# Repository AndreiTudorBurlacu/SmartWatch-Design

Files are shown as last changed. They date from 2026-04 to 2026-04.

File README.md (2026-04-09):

# Design Smartwatch

A smartwatch based on the Nordic nRF52840 microcontroller with an e-Paper display.
---

## Diagrama bloc

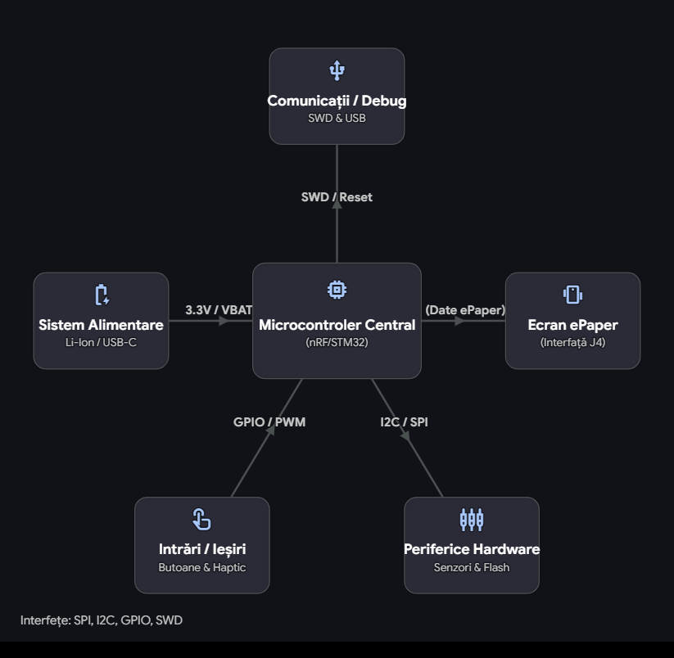
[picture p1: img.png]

---

## Bill of Materials

| Ref | Componenta | Valoare | JLC Parts | Datasheet |
|-----|---|---|---|---|
| U1 | nRF52840 | $5.12 | [JLC](https://jlcpcb.com/parts/componentSearch?searchTxt=nRF52840-QF) | [DS](https://jlcpcb.com/api/file/downloadByFileSystemAccessId/8589839228197629952) |
| X1 | NX2016SA-32MHZ-EXS00A-CS11336 | $9.06 | [JLC](https://jlcpcb.com/partdetail/NDK-NX2016SA_32MHZ_EXS00ACS11336/C6134317) | [DS](https://jlcpcb.com/api/file/downloadByFileSystemAccessId/8603064888214908928) |
| X2 | FC-135_32.7680KA-A3 | $0.2923 | [JLC](https://jlcpcb.com/partdetail/SeikoEpson-FC_135_32_7680KAA3/C2650472) | [DS](https://jlcpcb.com/partdetail/SeikoEpson-FC_135_32_7680KAA3/C2650472) |
| L2 | RC0402JR-070RL | $0.02 | [JLC](https://jlcpcb.com/partdetail/YAGEO-RC0402JR070RL/C60485) | [DS](https://jlcpcb.com/api/file/downloadByFileSystemAccessId/8717146932348461056) |
| L3 | RC0402JR-070RL | $0.01 | [JLC](https://jlcpcb.com/partdetail/YAGEO-RC0402JR070RL/C60485) | [DS](https://jlcpcb.com/api/file/downloadByFileSystemAccessId/8717146932348461056) |
| L5 | 744043680 | $9.33 | [JLC](https://jlcpcb.com/partdetail/WurthElektronik-744043680/C2045671) | [DS](https://www.we-online.com/components/products/datasheet/744043680.pdf) |
| L7 | MLP2016SR47MT0S1 | $0.9 | [JLC](https://jlcpcb.com/partdetail/TDK-MLP2016SR47MT0S1/C87545) | [DS](https://jlcpcb.com/api/file/downloadByFileSystemAccessId/8588933367512879104) |
| IC1 | BQ25180YBGR | $2.04 | [JLC](https://jlcpcb.com/partdetail/TexasInstruments-BQ25180YBGR/C3682423) | [DS](https://www.ti.com/cn/lit/gpn/bq25180) |
| IC2 | DRV2605YZFR | $1.61 | [JLC](https://jlcpcb.com/partdetail/TexasInstruments-DRV2605YZFR/C81079) | [DS](https://www.ti.com/cn/lit/gpn/drv2605) |
| IC3 | BMA423 | $12.30  | [JLC](https://jlcpcb.com/partdetail/BoschSensortec-BMA423/C189517) | [DS](https://jlcpcb.com/api/file/downloadByFileSystemAccessId/8588894317147017216) |
| IC9 | RT6160 | $0.46 | [JLC](https://jlcpcb.com/partdetail/RichtekTech-RT6160AWSC/C7065276) | [DS](https://jlcpcb.com/api/file/downloadByFileSystemAccessId/8600398231234883584) |
| ANT1 | 2450AT18B100E | $1.04 | [JLC](https://jlcpcb.com/partdetail/JohansonDielectrics-2450AT18B100E/C2917717) | [DS](https://jlcpcb.com/api/file/downloadByFileSystemAccessId/8588940948130156544) |
| D2 | MBR0530 | $0.02 | [JLC](https://jlcpcb.com/partdetail/78464-MBR0530/C77336) | [DS](https://jlcpcb.com/api/file/downloadByFileSystemAccessId/8586175081181818880) |
| D3 | USBLC6-2SC6Y | $0.23 | [JLC](https://jlcpcb.com/partdetail/STMicroelectronics-USBLC62SC6Y/C2969755) | [DS](https://jlcpcb.com/api/file/downloadByFileSystemAccessId/8603165824304111616) |
| D4 | MBR0530 | $0.03 | [JLC](https://jlcpcb.com/partdetail/78464-MBR0530/C77336) | [DS](https://jlcpcb.com/api/file/downloadByFileSystemAccessId/8586175081181818880) |
| D5 | MBR0530 | $0.04 | [JLC](https://jlcpcb.com/partdetail/78464-MBR0530/C77336) | [DS](https://jlcpcb.com/api/file/downloadByFileSystemAccessId/8586175081181818880) |
| Q1 | DMG2305UX-7 | $0.15 | [JLC](https://jlcpcb.com/partdetail/DiodesIncorporated-DMG2305UX7/C150470) | [DS](https://jlcpcb.com/api/file/downloadByFileSystemAccessId/8560079443617075200) |
| Q3 | SI1308EDL-T1-GE3 | $0.15 | [JLC](https://jlcpcb.com/partdetail/VishayIntertech-SI1308EDL_T1GE3/C469327) | [DS](https://jlcpcb.com/api/file/downloadByFileSystemAccessId/8588884784742846464) |
| J1 | 503480-2400 | $0.67 | [JLC](https://jlcpcb.com/partdetail/MOLEX-5034802400/C122434) | [DS](https://www.molex.com/content/dam/molex/molex-dot-com/products/automated/en-us/salesdrawingpdf/503/503480/5034802400_sd.pdf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) |
| J4 | KH-TYPE-C-16P | $0.05 | [JLC](https://jlcpcb.com/partdetail/Shenzhen_KinghelmElec-KH_TYPE_C16P/C709357) | [DS](https://jlcpcb.com/api/file/downloadByFileSystemAccessId/8588905154556923904) |
| U3 | MAX17048G-T10 | $2.76 | [JLC](https://jlcpcb.com/partdetail/2777647-MAX17048GT10/C2682616) | [DS](https://jlcpcb.com/api/file/downloadByFileSystemAccessId/8588907428524003328) |
| SWD | TC2030-IDC | $101.26 | [JLC](https://jlcpcb.com/partdetail/MicrochipTech-TC2030_CLIP3PACK/C5444772) | [DS](https://www.lcsc.com/datasheet/lcsc_datasheet_2403201318_Microchip-Tech-TC2030-CLIP-3PACK_C5444772.pdf) |

---

## Descriere Functionalitati Hardware

### Microcontroller - nRF52840

Arhitectura:
- Procesor ARM Cortex-M4 cu FPU ruland la 64 MHz
- 1 MB memorie Flash si 256 KB RAM
- Suport nativ pentru Bluetooth 5, Bluetooth Low Energy (BLE), Thread si Zigbee
- Dispune de USB 2.0 (Full Speed), SPI, I2C, UART si QSPI
 
### Display E-Paper - Waveshare 1.54" V2
 
Display-ul comunica prin SPI pe 4 fire:
- Rezolutie: 200x200 pixeli
- Interfata comunicare: SPI
- Consum de energie ultra-redus; consuma aproximativ 26.4 mW doar in timpul reimprospatarii si scade sub 0.01 uA in modul standby
- Suporta partial refresh (reimprospatarea doar a unei anumite zone din ecran)
 
### IMU - BMA423
 
Accelerometrul BMA423 comunica prin I2C:

- Tip senzor: Accelerometru digital pe 3 axe.
- Rezolutie date - 12 biti
- Interfete comunicare: I2C si SPI
- Consum foarte eficient, trage in jur de 14 uA cand se afla in modul activ de numarare a pasilor
 
### Incarcator Baterie - BQ25180

- Dimensiuni: 32.5mm x 21mm x 5.5mm
- Curent de incarcare: Flexibil, poate incarca de la cativa miliamperi pana la 1 A
- Interfata control: Comunicare I2C prin care procesorul principal poate citi statusul bateriei si poate modifica parametrii de incarcare din mers
- Tensiune standard de intrare de 5V, dar are protectie la supratensiune (OVP) care rezista pana la 25V
 
### Baterie - AKYGA LP502030
 
- Tensiune - 3.7V nominal (ajunge la 4.2V cand este incarcata 100% si scade spre 3.0V cand este descarcata)
- Capacitate: Aproximativ 250 mAh
- Dimensiuni - 5 mm x 20 mm x 30 mm
 
### Motor Vibratii - FIT0774

- Tensiune de operare: 3V curent continuu
- Curent maxim consumat - 85 mA in momentul in care vibreaza la capacitate maxima
- Viteza de rotatie: Aproximativ 12000 RPM
- 10 mm diametru si o grosime de doar 2.7 mm
 
### Conector Debug - TC2030-IDC
 
- Tip contact: 6 pini cu arc (pogo-pins) dispusi pe 2 randuri, cu o distanta de 1.27 mm intre ei
- Folosit pentru programare si debugging SWD
- Semnale: SWDIO, SWDCLK, GND, VCC, RESET
 
---
 
## Pinii nRF52840
 
| Pin nRF52840 | Semnal | Componenta | Interfata |
|---|---|---|---|
| P0.00/XL1 | XL1 | Crystal X2 (32.768kHz) | XTAL |
| P0.01/XL2 | XL2 | Crystal X2 (32.768kHz) | XTAL |
| P0.05/AIN3 | EPD_CS | E-Paper (J1 FPC) | SPI CS |
| P0.06 | SDA | BMA423, BQ25180, MAX17048, DRV2605 | I2C SDA |
| P0.07 | SCL | BMA423, BQ25180, MAX17048, DRV2605 | I2C SCL |
| P0.08 | IMU_INT1 | BMA423 | GPIO Input |
| P1.08 | IMU_INT2 | BMA423 | GPIO Input |
| P0.11 | PMIC_INT | BQ25180 | GPIO Input |
| P0.12 | HAPTIC_EN | DRV2605 | GPIO |
| VBUS | VBUS | USB-C (J4) | Power |
| D- | D- | USB-C (J4) / USBLC6 | USB |
| D+ | D+ | USB-C (J4) / USBLC6 | USB |
| P0.13 | SW_UP | Buton Up | GPIO Input |
| P0.14 | SW_ENT | Buton Enter | GPIO Input |
| P0.15 | EPD_DC | E-Paper (J1 FPC) | SPI DC |
| P0.16 | EPD_RST | E-Paper (J1 FPC) | GPIO |
| P0.17 | EPD_BUSY | E-Paper (J1 FPC) | GPIO Input |
| P0.18/RESET | RESET | TC2030-IDC | SWD/GPIO |
| SWDCLK | SWDCLK | TC2030-IDC | SWD |
| SWDIO | SWDIO | TC2030-IDC | SWD |
| P1.02 | SW_DN | Buton Down | GPIO Input |
| P0.10/NFC2 | ALERT | MAX17048 | GPIO Input |
| ANT | RF | Antena 2450AT18B100E | RF |
| P0.02/AIN0 | SCK | E-Paper (J1 FPC) | SPI SCK |
| P0.03/AIN1 | MOSI | E-Paper (J1 FPC) | SPI MOSI |

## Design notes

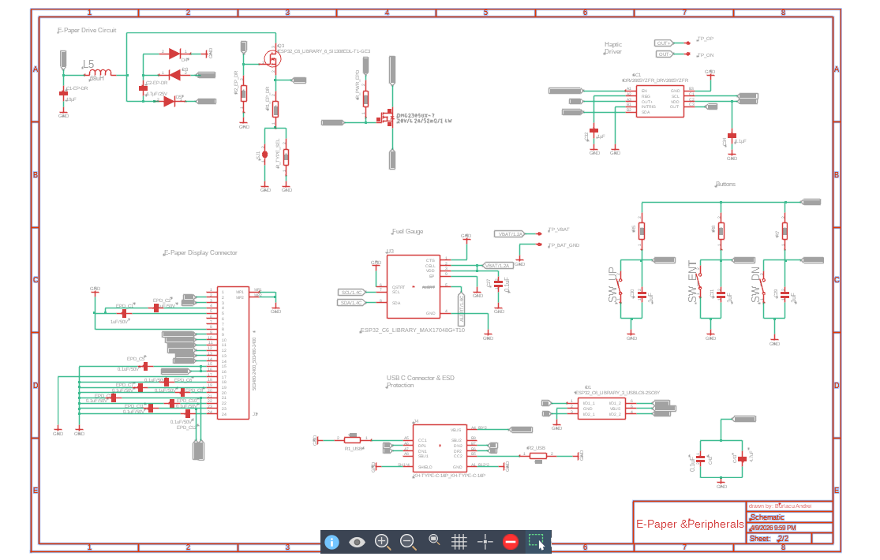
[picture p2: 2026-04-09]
Images/Schematic2.png

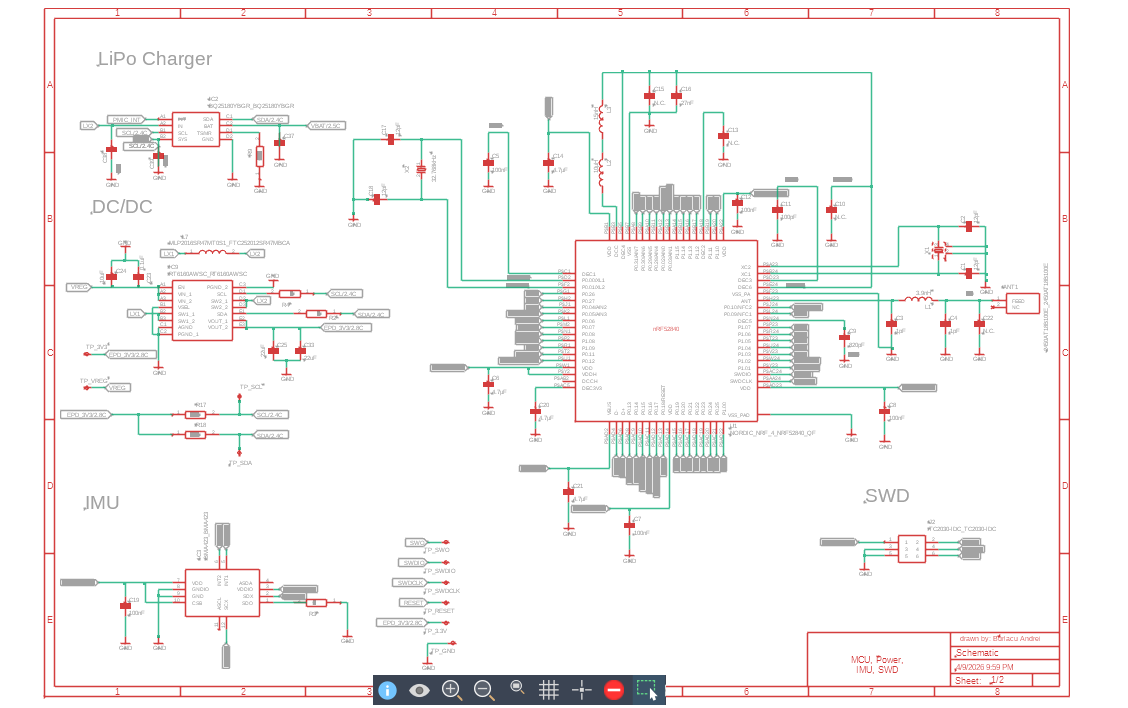
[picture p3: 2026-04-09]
Images/Schematic1.png

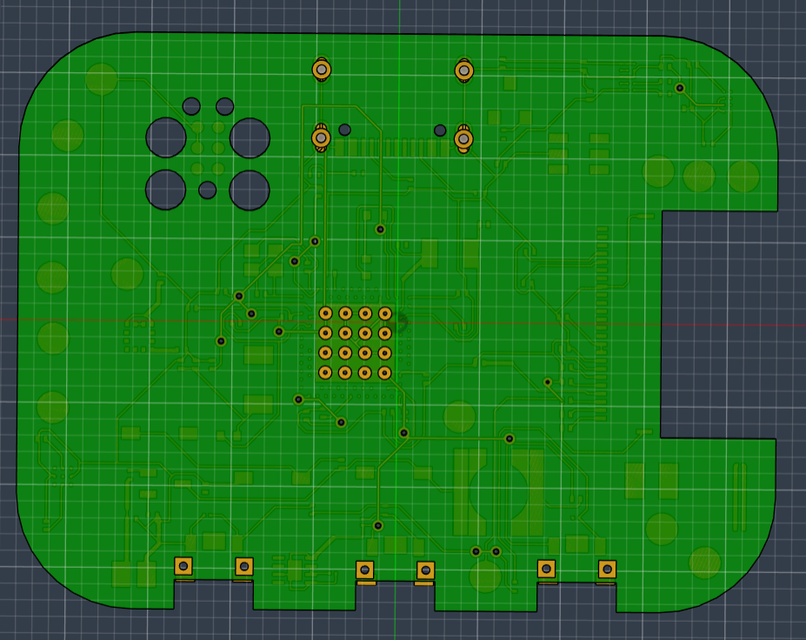
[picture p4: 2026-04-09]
Images/PCB_spate.png

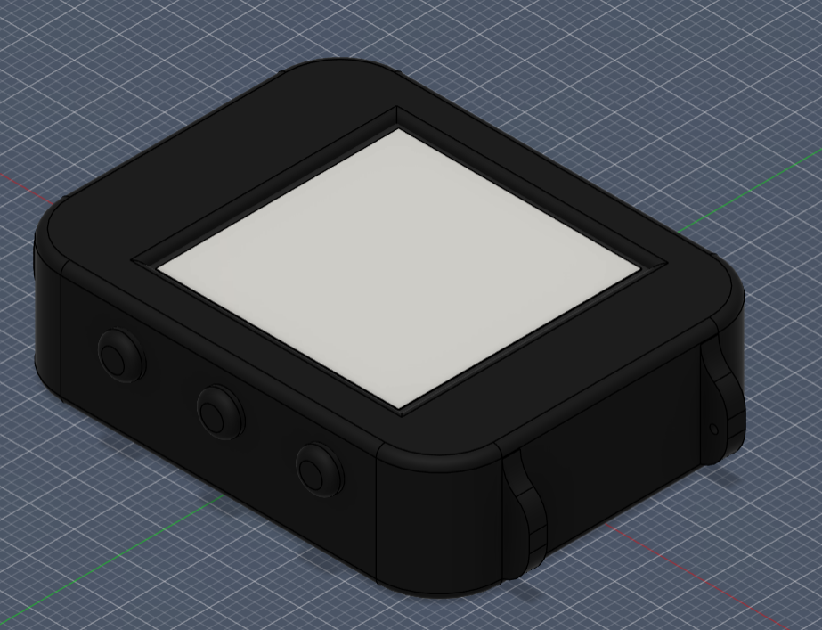
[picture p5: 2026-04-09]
Images/WatchCase3D.png

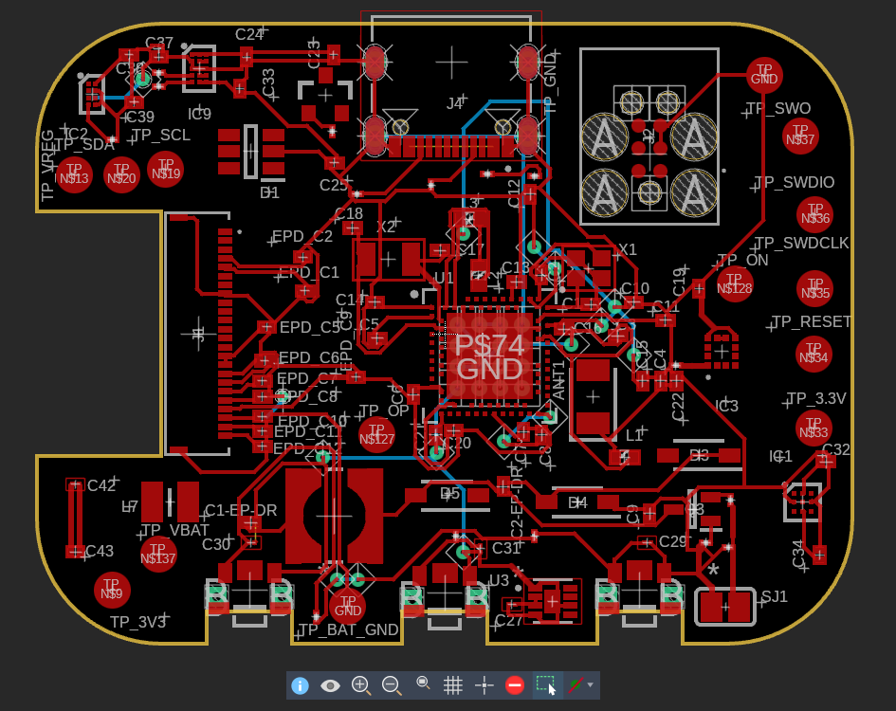
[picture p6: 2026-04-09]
Images/PCB.png

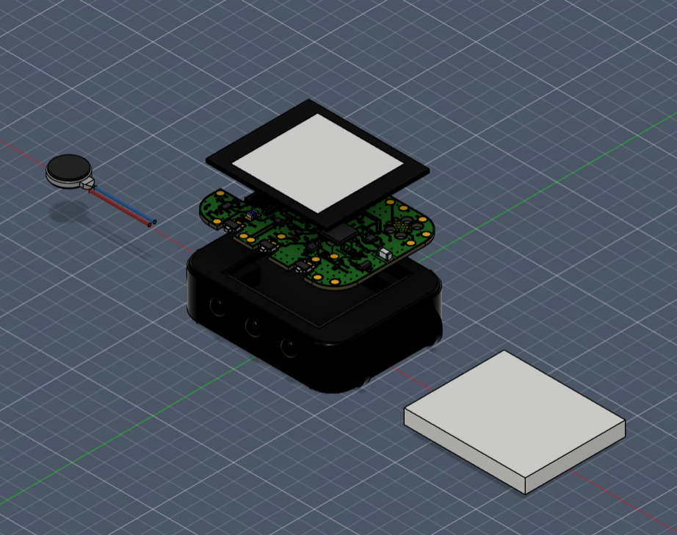
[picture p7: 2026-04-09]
Images/ExplodedView.png

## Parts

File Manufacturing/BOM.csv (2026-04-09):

Reference Designators | Quantity | Description | Package | Value | Manufacturer | Manufacturer Part Number | Vendor | Vendor Part Number | Top/Bottom
 | 1 | PCB Board | Board
ANT1 | 1 | Antennas 2.45GHz ANTENNA | 2450AT18B100E_ANTC3216X140N | 2450AT18B100E_2450AT18B100E |  |  |  |  | Top
C1, C2, C17, C18 | 4 | Generic chip capacitor | NORDIC_NRF_3_RESC0201_L | 12pF |  |  |  |  | Top
C1-EP-DR | 1 | Generic chip capacitor | NORDIC_NRF_3_RESC0201_L | 10µF |  |  |  |  | Top
C2-EP-DR | 1 | Generic chip capacitor | NORDIC_NRF_3_RESC0201_L | 4.7µF/25V |  |  |  |  | Top
C3, C4 | 2 | Generic chip capacitor | NORDIC_NRF_3_RESC0201_L | 1pF |  |  |  |  | Top
C5, C7, C8, C12, C19 | 5 | Generic chip capacitor | NORDIC_NRF_3_RESC0201_L | 100nF |  |  |  |  | Top
C6, C14, C20, C21 | 4 | Generic chip capacitor | NORDIC_NRF_3_RESC0201_L | 4.7µF |  |  |  |  | Top
C9 | 1 | Generic chip capacitor | NORDIC_NRF_3_RESC0201_L | 820pF |  |  |  |  | Top
C10, C13, C15, C22 | 4 | Generic chip capacitor | NORDIC_NRF_3_RESC0201_L | N.C. |  |  |  |  | Top
C11 | 1 | Generic chip capacitor | NORDIC_NRF_3_RESC0201_L | 100pF |  |  |  |  | Top
C16 | 1 | Generic chip capacitor | NORDIC_NRF_3_RESC0201_L | 27nF |  |  |  |  | Top
C23 | 1 | Generic chip capacitor | NORDIC_NRF_3_RESC0201_L | 0.1uF |  |  |  |  | Top
C24 | 1 | Generic chip capacitor | NORDIC_NRF_3_RESC0201_L | 10uF |  |  |  |  | Top
C25, C33 | 2 | Generic chip capacitor | NORDIC_NRF_3_RESC0201_L | 22uF |  |  |  |  | Top
C27, C29, C30, C31, C42 | 5 | Check availability | CAPC0201X13N | GRM011R60J152KE01L_2_GRM011R60J152KE01L |  |  |  |  | Top
C32 | 1 | Generic chip capacitor | NORDIC_NRF_3_RESC0201_L | 1µF |  |  |  |  | Top
C34 | 1 | Generic chip capacitor | NORDIC_NRF_3_RESC0201_L | 0.1µF |  |  |  |  | Top
C37, C38, C39 | 3 | Generic chip capacitor | NORDIC_NRF_3_RESC0201_L |  |  |  |  |  | Top
C43 | 1 | Generic chip capacitor | NORDIC_NRF_3_RESC0201_L | 4.7uF |  |  |  |  | Top
D1 | 1 | Low Cap. ESD Protection Auto SOT-23-6 STMicroelectronics USBLC6-2SC6Y, Dual Uni-Directional TVS Diode Array, 6-Pin SOT-23 | SOT95P280X145-6N | ESP32_C6_LIBRARY_3_USBLC6-2SC6Y |  |  |  |  | Top
D3, D4, D5 | 3 | ON SEMICONDUCTOR - MBR0530 - DIODE, SCHOTTKY, 0.5A, 30V, SOD-123 | SOD3716X135N | ESP32_C6_LIBRARY_5_MBR0530 |  |  |  |  | Top
DMG2305UX-7 | 1 | P-channel MOSFETs | ESP32_WROVER_SPARKFUN-DISCRETESEMI_SOT23-3 | 20V/4.2A/52mΩ/1.4W |  |  |  |  | Top
EPD_C1, EPD_C2 | 2 | Generic chip capacitor | NORDIC_NRF_3_RESC0201_L | 1uF/50V |  |  |  |  | Top
EPD_C5, EPD_C6, EPD_C7, EPD_C8, EPD_C9, EPD_C10, EPD_C11, EPD_C12 | 8 | Generic chip capacitor | NORDIC_NRF_3_RESC0201_L | 0.1uF/50V |  |  |  |  | Top
IC1 | 1 | Haptic Driver for ERM/LRA with Built-In Library and Smart Loop Architecture | DRV2605YZFR_BGA9C50P3X3_144X144X62 | DRV2605YZFR_DRV2605YZFR |  |  |  |  | Top
IC2 | 1 | Charger IC Lithium Ion/Polymer, Lithium Iron Phosphate 8-DSBGA (1.6x1.1) | BQ25180YBGR_BGA8C40P2X4_100X155X50 | BQ25180YBGR_BQ25180YBGR |  |  |  |  | Top
IC3 | 1 | Accelerometers Triaxial low-g 12bit Acceleration Sensor | BMA423_BMA423 | BMA423_BMA423 |  |  |  |  | Top
IC9 | 1 | Buck-Boost Regulator Positive Output Step-Up/Step-Down I2C DC-DC Controller IC 15-WL-CSP (BSC) (1.4x2.3) | RT6160AWSC_BGA15C40P3X5_140X230X60 | RT6160AWSC_RT6160AWSC |  |  |  |  | Top
J1 | 1 | FFC & FPC Connectors 0.5mm FPC RA SMT Dual Contact 24Ckt | 503480-2400_5034802400 | 503480-2400_503480-2400 |  |  |  |  | Top
J2 | 1 | CABLE ADAPTER 6 POS | TC2030-IDC_TC2030IDC | TC2030-IDC_TC2030-IDC |  |  |  |  | Top
J4 | 1 | Check availability | KINGHELM_KH-TYPE-C-16P | KH-TYPE-C-16P_KH-TYPE-C-16P |  |  |  |  | Top
L1 | 1 | Generic chip inductor | NORDIC_NRF_2_RESC0402_L | 3.9nH |  |  |  |  | Top
L2 | 1 | Generic chip inductor | NORDIC_NRF_2_RESC0402_L | 10µH |  |  |  |  | Top
L3 | 1 | Generic chip inductor | NORDIC_NRF_2_RESC0402_L | 15nH |  |  |  |  | Top
L5 | 1 |  | ESP32_C6_LIBRARY_2_IND_4828-WE-TPC_WRE | 68uH |  |  |  |  | Top
L7 | 1 | SMD / SMT Inductors (Coils), L=0.47?H, L x W x T : | MLP2016SR47MT0S1_INDC2016X100N | MLP2016SR47MT0S1_FTC252012SR47MBCA |  |  |  |  | Top
Q3 | 1 | MOSFET N-Ch 30V 1.5A TrenchFET SC70 Vishay Si1308EDL-T1-GE3 N-channel MOSFET Transistor, 1.5 A, 30 V, 3-Pin SC-70 | SOT65P210X110-3N | ESP32_C6_LIBRARY_6_SI1308EDL-T1-GE3 |  |  |  |  | Top
R_PWR_EPD, R_TYPE_SEL, R1_EP_DR, R1_USB, R2, R2_EP_DR, R2_USB, R3, R4, R5, R7, R8, R9, R17, R18 | 15 | 7.68k 0201 Thin Film Surface Mount Fixed Resistor +/-0.5% 0.031W CPF0201D7K68C1 | R0201 | ERA-1AEB3401C_CPF0201D7K68C1 |  |  |  |  | Top
SJ1 | 1 | SMD solder JUMPER | JUMPER_SJ |  |  |  |  |  | Top
SW_DN, SW_ENT, SW_UP | 3 |  | SW_EVP-AKE31A_PAN | 2025-10-22_07-23-44_LIBRARY_EVP-AKE31ASW_EVP-AKE31A_PAN |  |  |  |  | Top
TP_3.3V, TP_3V3, TP_BAT_GND, TP_GND, TP_ON, TP_OP, TP_RESET, TP_SCL, TP_SDA, TP_SWDCLK, TP_SWDIO, TP_SWO, TP_VBAT, TP_VREG | 14 | Test pad | HECTOR_WATCH_1_TP20R | HECTOR_WATCH_1_TPTP20R |  |  |  |  | Top
U1 | 1 | nRF52840 | NORDIC_NRF_4_AQFN50P700X700X85_HS-74N | NORDIC_NRF_4_NRF52840_QF |  |  |  |  | Top
U3 | 1 | Check availability | SON50P200X200X80-9N | ESP32_C6_LIBRARY_MAX17048G+T10 |  |  |  |  | Top
X1 | 1 |  | NORDIC_NRF_BT-XTAL_2016_N |  |  |  |  |  | Top
X2 | 1 |  | NORDIC_NRF_1_XTAL_3215_N | 32.768kHz |  |  |  |  | Top

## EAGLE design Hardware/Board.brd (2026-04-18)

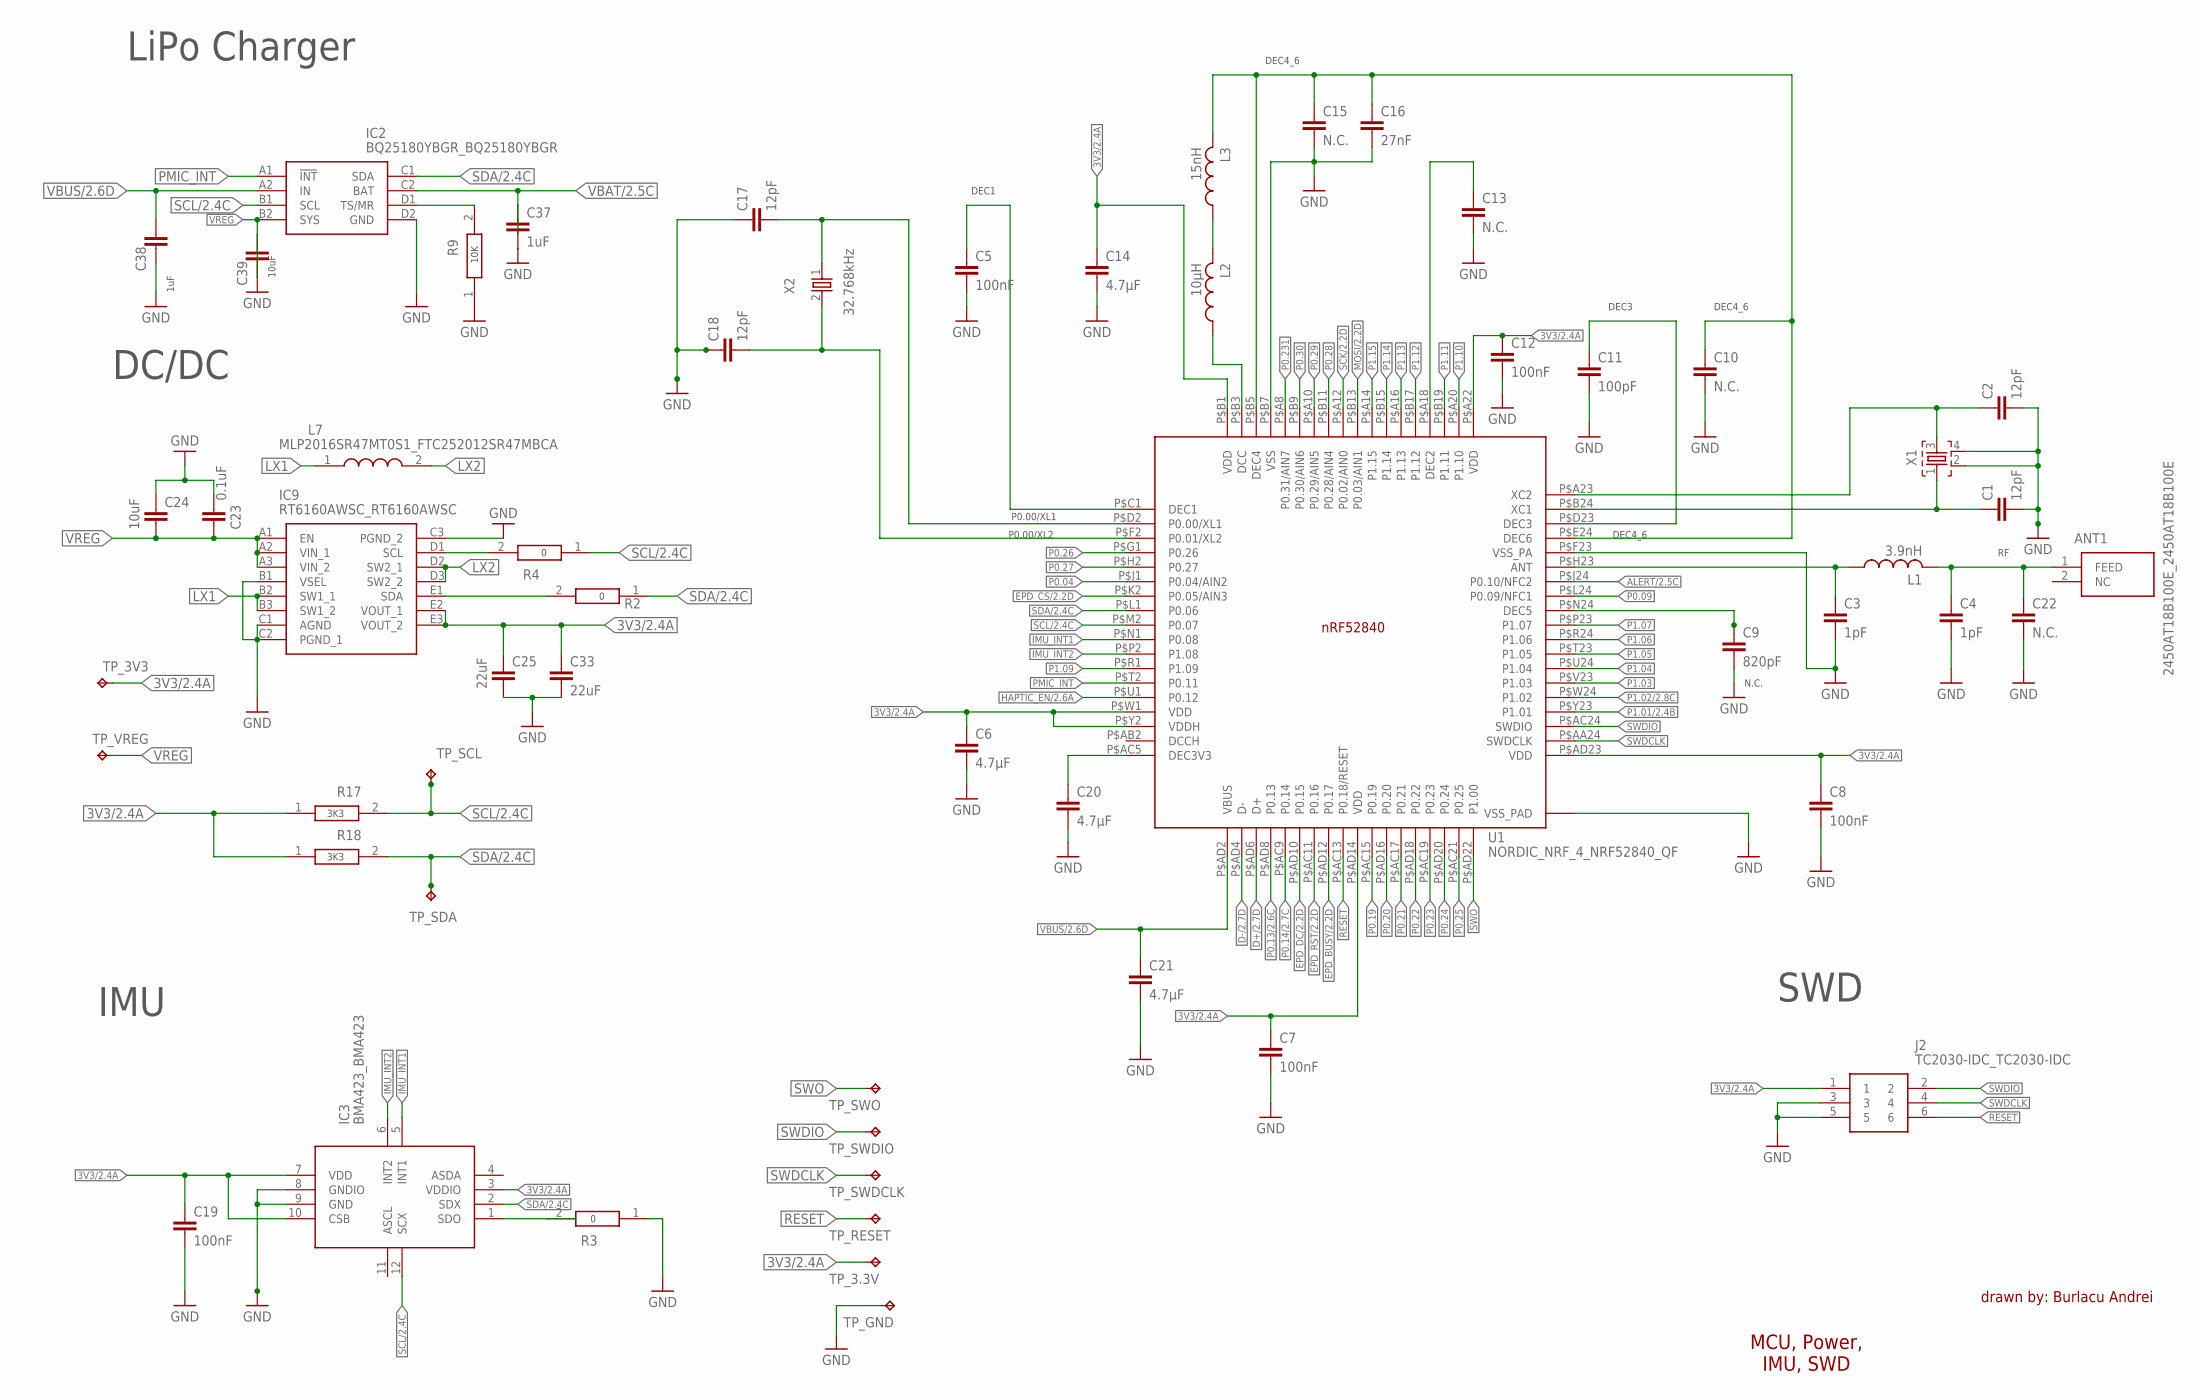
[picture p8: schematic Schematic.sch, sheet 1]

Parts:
ANT1: 2450AT18B100E_2450AT18B100E; 2450AT18B100E_ANTC3216X140N
C1, C2, C17, C18: 12pF; NORDIC_NRF_3_RESC0201_L
C3, C4: 1pF; NORDIC_NRF_3_RESC0201_L
C5, C7, C8, C12, C19: 100nF; NORDIC_NRF_3_RESC0201_L
C6, C14, C20, C21: 4.7µF; NORDIC_NRF_3_RESC0201_L
C9: 820pF; NORDIC_NRF_3_RESC0201_L
C10, C13, C15, C22: N.C.; NORDIC_NRF_3_RESC0201_L
C11: 100pF; NORDIC_NRF_3_RESC0201_L
C16: 27nF; NORDIC_NRF_3_RESC0201_L
C23: 0.1uF; NORDIC_NRF_3_RESC0201_L
C24: 10uF; NORDIC_NRF_3_RESC0201_L
C25, C33: 22uF; NORDIC_NRF_3_RESC0201_L
C37: 1uF; NORDIC_NRF_3_RESC0201_L
C38, C39: NORDIC_NRF_3_CAPACITOR_0201_L; NORDIC_NRF_3_RESC0201_L
IC2: BQ25180YBGR_BQ25180YBGR; BQ25180YBGR_BGA8C40P2X4_100X155X50
IC3: BMA423_BMA423
IC9: RT6160AWSC_RT6160AWSC; RT6160AWSC_BGA15C40P3X5_140X230X60
J2: TC2030-IDC_TC2030-IDC; TC2030-IDC_TC2030IDC
L1: 3.9nH; NORDIC_NRF_2_RESC0402_L
L2: 10µH; NORDIC_NRF_2_RESC0402_L
L3: 15nH; NORDIC_NRF_2_RESC0402_L
L7: MLP2016SR47MT0S1_FTC252012SR47MBCA; MLP2016SR47MT0S1_INDC2016X100N
R2, R3, R4, R9, R17, R18: ERA-1AEB3401C_CPF0201D7K68C1; ERA-1AEB3401C_0201
TP_3.3V, TP_3V3: HECTOR_WATCH_1_TPTP20R; HECTOR_WATCH_1_TP20R
TP_GND: HECTOR_WATCH_1_TPTP20R; HECTOR_WATCH_1_TP20R
TP_RESET: HECTOR_WATCH_1_TPTP20R; HECTOR_WATCH_1_TP20R
TP_SCL: HECTOR_WATCH_1_TPTP20R; HECTOR_WATCH_1_TP20R
TP_SDA: HECTOR_WATCH_1_TPTP20R; HECTOR_WATCH_1_TP20R
TP_SWDCLK: HECTOR_WATCH_1_TPTP20R; HECTOR_WATCH_1_TP20R
TP_SWDIO: HECTOR_WATCH_1_TPTP20R; HECTOR_WATCH_1_TP20R
TP_SWO: HECTOR_WATCH_1_TPTP20R; HECTOR_WATCH_1_TP20R
TP_VREG: HECTOR_WATCH_1_TPTP20R; HECTOR_WATCH_1_TP20R
U1: NORDIC_NRF_4_NRF52840_QF; NORDIC_NRF_4_AQFN50P700X700X85_HS-74N
X1: NORDIC_NRF_XTAL_32MHZ; NORDIC_NRF_BT-XTAL_2016_N
X2: 32.768kHz; NORDIC_NRF_1_XTAL_3215_N

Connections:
GND: C3.2, C4.2, C5.2, C6.2, C7.2, C8.2, C9.2, C10.2, C11.2, C12.2, C13.2, C14.2, C15.2, C16.2, C19.2, C20.2, C21.2, C22.2, C23.1, C24.1, C25.2, C33.2, C37.2, C38.2, C39.1, C39.2, IC2.B2 (SYS), IC2.D2 (GND), IC9.B1 (VSEL), IC9.C1 (AGND), IC9.C2 (PGND_1), IC9.C3 (PGND_2), J2.3, J2.5, R3.1, R9.1, TP_GND.TP, U1.P$74 (VSS_PAD), U1.P$75 (VSS_PAD), U1.P$76 (VSS_PAD), U1.P$77 (VSS_PAD), U1.P$78 (VSS_PAD), U1.P$79 (VSS_PAD), U1.P$80 (VSS_PAD), U1.P$81 (VSS_PAD), U1.P$82 (VSS_PAD), U1.P$83 (VSS_PAD), U1.P$84 (VSS_PAD), U1.P$85 (VSS_PAD), U1.P$86 (VSS_PAD), U1.P$87 (VSS_PAD), U1.P$88 (VSS_PAD), U1.P$89 (VSS_PAD), U1.P$90 (VSS_PAD), U1.P$B7 (VSS), U1.P$F23 (VSS_PA); also elsewhere on the board
unnamed: IC2.D1 (TS/MR), R9.2
unnamed: C38.1, IC2.A2 (IN)
unnamed: C37.1, IC2.C2 (BAT)
unnamed: C23.2, C24.2, IC9.A1 (EN), IC9.A2 (VIN_1), IC9.A3 (VIN_2)
unnamed: IC9.B2 (SW1_1), IC9.B3 (SW1_2)
unnamed: IC9.D1 (SCL), R4.2
unnamed: R17.1, R18.1
unnamed: IC9.D2 (SW2_1), IC9.D3 (SW2_2)
unnamed: C25.1, C33.1, IC9.E2 (VOUT_1), IC9.E3 (VOUT_2)
unnamed: IC9.E1 (SDA), R2.2
unnamed: C19.1, IC3.7 (VDD), IC3.10 (CSB)
unnamed: IC3.8 (GNDIO), IC3.9 (GND)
unnamed: IC3.1 (SDO), R3.2
unnamed: C7.1, U1.P$AD14 (VDD)
unnamed: C21.1, U1.P$AD2 (VBUS)
unnamed: C8.1, U1.P$AD23 (VDD)
unnamed: C3.1, L1.1, U1.P$H23 (ANT)
unnamed: ANT1.1 (FEED), C4.1, C22.1, L1.2
unnamed: C10.1, C15.1, C16.1, L3.2, U1.P$B5 (DEC4), U1.P$E24 (DEC6)
unnamed: C11.1, U1.P$D23 (DEC3)
unnamed: C1.1, U1.P$B24 (XC1), X1.1
unnamed: C2.1, U1.P$A23 (XC2), X1.3
unnamed: C1.2, C2.2, X1.2, X1.4
unnamed: C12.1, U1.P$A22 (VDD)
unnamed: C13.1, U1.P$A18 (DEC2)
unnamed: L2.2, L3.1
unnamed: L2.1, U1.P$B3 (DCC)
unnamed: C20.1, U1.P$AC5 (DEC3V3)
unnamed: C6.1, U1.P$W1 (VDD), U1.P$Y2 (VDDH)
unnamed: C14.1, U1.P$B1 (VDD)
unnamed: C5.1, U1.P$C1 (DEC1)
unnamed: C17.2, U1.P$D2 (P0.00/XL1), X2.1
unnamed: C18.2, U1.P$F2 (P0.01/XL2), X2.2
SDA/2.4C: IC2.C1 (SDA)

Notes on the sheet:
LiPo Charger
10K
DC/DC
3K3
10uF
1uF
IMU
N.C.
DEC3
DEC4_6
DEC1
P0.00/XL1
P0.00/XL2
drawn by: Burlacu Andrei
MCU, Power, IMU, SWD
SWD

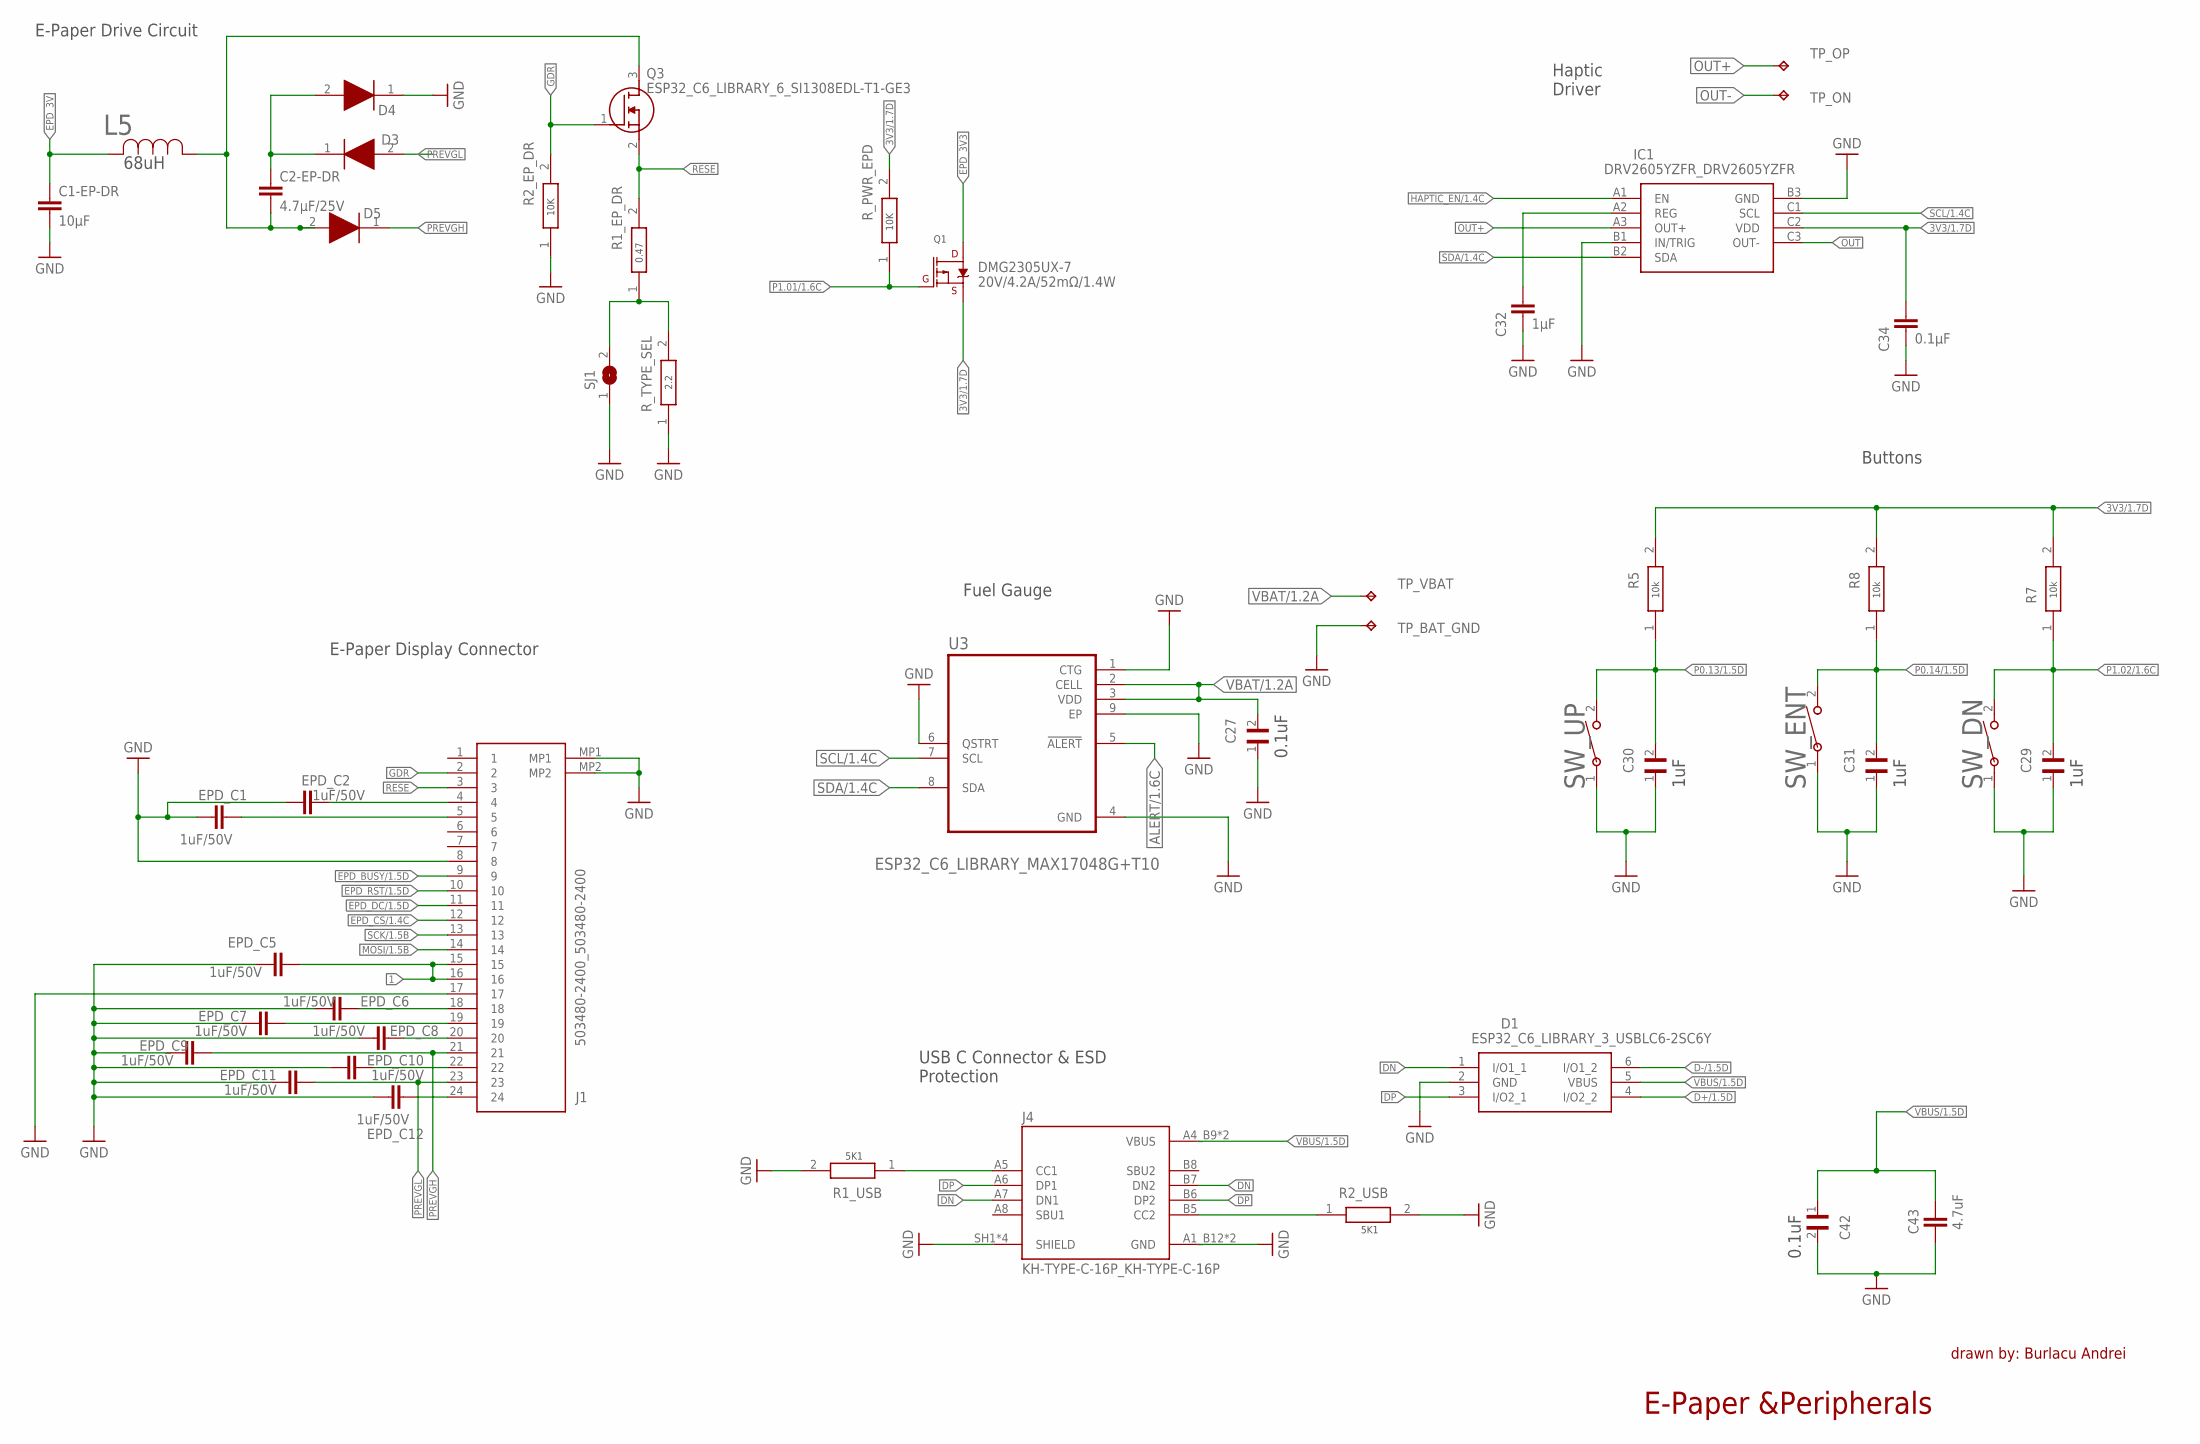
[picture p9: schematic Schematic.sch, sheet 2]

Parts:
C1-EP-DR: 10µF; NORDIC_NRF_3_RESC0201_L
C2-EP-DR: 4.7µF/25V; NORDIC_NRF_3_RESC0201_L
C27, C29, C30, C31, C42: GRM011R60J152KE01L_2_GRM011R60J152KE01L; GRM011R60J152KE01L_2_CAPC0201X13N
C32: 1µF; NORDIC_NRF_3_RESC0201_L
C34: 0.1µF; NORDIC_NRF_3_RESC0201_L
C43: 4.7uF; NORDIC_NRF_3_RESC0201_L
D1: ESP32_C6_LIBRARY_3_USBLC6-2SC6Y; ESP32_C6_LIBRARY_3_SOT95P280X145-6N
D3, D4, D5: ESP32_C6_LIBRARY_5_MBR0530; ESP32_C6_LIBRARY_5_SOD3716X135N
DMG2305UX-7: 20V/4.2A/52mΩ/1.4W; ESP32_C6_LIBRARY_4_ESP32_C6_LIBRARY_4_ESP32_C6_LIBRARY_4_ES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
EPD_C1, EPD_C2, EPD_C5, EPD_C6, EPD_C7, EPD_C8, EPD_C9, EPD_C10, EPD_C11, EPD_C12: 1uF/50V; NORDIC_NRF_3_RESC0201_L
IC1: DRV2605YZFR_DRV2605YZFR; DRV2605YZFR_BGA9C50P3X3_144X144X62
J1: 503480-2400_503480-2400; 503480-2400_5034802400
J4: KH-TYPE-C-16P_KH-TYPE-C-16P; KH-TYPE-C-16P_KINGHELM_KH-TYPE-C-16P
L5: 68uH; ESP32_C6_LIBRARY_2_IND_4828-WE-TPC_WRE
Q3: ESP32_C6_LIBRARY_6_SI1308EDL-T1-GE3; ESP32_C6_LIBRARY_6_SOT65P210X110-3N
R1_EP_DR, R1_USB, R2_EP_DR, R2_USB, R5, R7, R8: ERA-1AEB3401C_CPF0201D7K68C1; ERA-1AEB3401C_0201
R_PWR_EPD: ERA-1AEB3401C_CPF0201D7K68C1; ERA-1AEB3401C_0201
R_TYPE_SEL: ERA-1AEB3401C_CPF0201D7K68C1; ERA-1AEB3401C_0201
SJ1: ESP32_C6_LIBRARY_7_JUMPER_SJ
SW_DN: 2025-10-22_07-23-44_LIBRARY_EVP-AKE31ASW_EVP-AKE3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; 2025-10-22_07-23-44_LIBRARY_SW_EVP-AKE31A_PAN
SW_ENT: 2025-10-22_07-23-44_LIBRARY_EVP-AKE31ASW_EVP-AKE3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; 2025-10-22_07-23-44_LIBRARY_SW_EVP-AKE31A_PAN
SW_UP: 2025-10-22_07-23-44_LIBRARY_EVP-AKE31ASW_EVP-AKE3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; 2025-10-22_07-23-44_LIBRARY_SW_EVP-AKE31A_PAN
TP_BAT_GND: HECTOR_WATCH_1_TPTP20R; HECTOR_WATCH_1_TP20R
TP_ON: HECTOR_WATCH_1_TPTP20R; HECTOR_WATCH_1_TP20R
TP_OP: HECTOR_WATCH_1_TPTP20R; HECTOR_WATCH_1_TP20R
TP_VBAT: HECTOR_WATCH_1_TPTP20R; HECTOR_WATCH_1_TP20R
U3: ESP32_C6_LIBRARY_MAX17048G+T10; ESP32_C6_LIBRARY_SON50P200X200X80-9N

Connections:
GND: C1-EP-DR.2, C27.1, C29.1, C30.1, C31.1, C32.2, C34.2, D1.2 (GND), D4.1 (K), EPD_C1.1, EPD_C2.1, EPD_C5.1, EPD_C6.1, EPD_C7.1, EPD_C8.1, EPD_C9.1, EPD_C10.1, EPD_C11.1, EPD_C12.1, IC1.B1 (IN/TRIG), IC1.B3 (GND), J1.8, J1.17, J1.MP1, J1.MP2, J4.A1_B12 (GND), J4.A12_B1 (GND), J4.SH1 (SHIELD), J4.SH2 (SHIELD), J4.SH3 (SHIELD), J4.SH4 (SHIELD), R1_USB.2, R2_EP_DR.1, R2_USB.2, R_TYPE_SEL.1, SJ1.1, SW_DN.1, SW_ENT.1, SW_UP.1, TP_BAT_GND.TP, U3.1 (CTG), U3.4 (GND), U3.6 (QSTRT), U3.9 (EP); also elsewhere on the board
GND1: R1_EP_DR.1, R_TYPE_SEL.2, SJ1.2
GND2: C29.2, R7.1, SW_DN.2
GND3: C31.2, R8.1, SW_ENT.2
GND4: C30.2, R5.1, SW_UP.2
unnamed: C1-EP-DR.1, L5.2
unnamed: C2-EP-DR.2, D5.2 (A), L5.1, Q3.3 (D)
unnamed: C2-EP-DR.1, D3.1 (K), D4.2 (A)
unnamed: Q3.1 (G), R2_EP_DR.2
unnamed: Q3.2 (S), R1_EP_DR.2
unnamed: DMG2305UX-7.1 (G), R_PWR_EPD.1
unnamed: C32.1, IC1.A2 (REG)
unnamed: C34.1, IC1.C2 (VDD)
unnamed: R5.2, R7.2, R8.2
unnamed: C27.2, U3.2 (CELL), U3.3 (VDD)
unnamed: EPD_C12.2, J1.24
unnamed: EPD_C2.2, J1.4
unnamed: EPD_C1.2, J1.5
unnamed: EPD_C5.2, J1.15, J1.16
unnamed: EPD_C11.2, J1.23
unnamed: EPD_C10.2, J1.22
unnamed: EPD_C9.2, J1.21
unnamed: EPD_C8.2, J1.20
unnamed: EPD_C7.2, J1.19
unnamed: EPD_C6.2, J1.18
unnamed: J4.A4_B9 (VBUS), J4.A9_B4 (VBUS)
unnamed: J4.B5 (CC2), R2_USB.1
unnamed: J4.A5 (CC1), R1_USB.1
unnamed: C42.2, C43.1
unnamed: C42.1, C43.2

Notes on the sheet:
E-Paper Drive Circuit
10K
0.47
2.2
68uH
Haptic Driver
Buttons
10k
1uF
Fuel Gauge
0.1uF
E-Paper Display Connector
USB C Connector & ESD Protection
5K1
E-Paper &Peripherals
drawn by: Burlacu Andrei

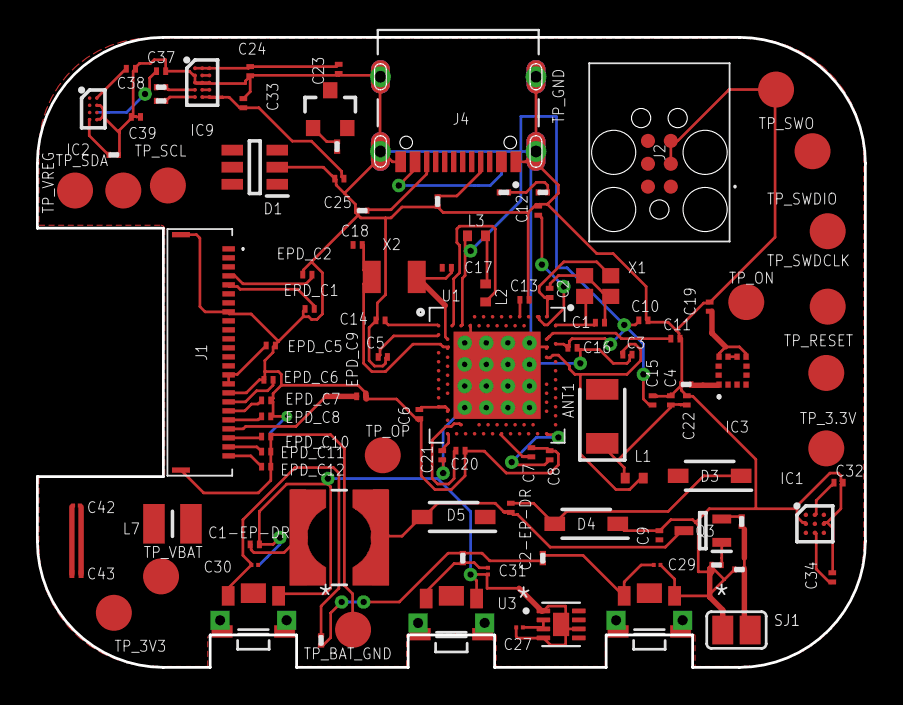
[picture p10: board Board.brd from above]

Board: 2 copper layers, 46.0 x 35.0 mm, 105 parts (0 on the bottom side), 63 nets.

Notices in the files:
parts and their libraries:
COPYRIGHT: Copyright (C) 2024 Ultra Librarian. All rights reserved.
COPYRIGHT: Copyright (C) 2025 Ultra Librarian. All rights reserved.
